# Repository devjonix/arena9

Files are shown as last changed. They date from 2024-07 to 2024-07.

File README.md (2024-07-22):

# Arena 9

Arena 9 is a camera setup for fly walking experiments.
It currently consists of three modules

- Top: Mounting for a camera and LEDs
- Middle: The actual arena (9 cm diam) and its holder
- Bottom: A lift mechanism

The arena is still under development and parts may change
(as of July 2024).

## Function of each module

### Top

The top module creates distance to the arena and acts as a mounting point
for the camera.

The LED slots allow optogenetic stimulation and
illumination of the flies.

### Middle

Contains the actual arena and its holder.
The arena slides out for easy fly loading and unloading.

The floor and ceiling are acrylic glass sheets.

### Bottom

#### A) Lift (optional)

The bottom has a elevator mechanism for moving the arena up and
down. This is needed when using a video projector and a back-projection screen to adjust the distance to the screen.

Sanded or somehow else mattefied acrylic glass sheet can act
as the back-projection screen.

## DIY manufacturing

The arena is mostly 3D printable and requires only a minimal
set of additional parts. You will need

- Any FDM 3D printer
- About 1 kg of PET-G, PLA or other filament

Tested with 0.2 mm layer height, 0.4 mm nozzle and slicer
default settings. Parts do not require supports.
Brims or rafts can be used if needed for good bed adhesion.

Required, non-printable parts

- Many M3 hex-socket screws, length 8 mm
- 3x 95 x 95 x 2 mm acrylic glass

Screw holes have tight tolerances so that the M3 screws
essentially drill in.

Yet unfixed components

- USB camera for video capture (fly tracking)
- Light sources for illumination and optogenetic activation
- A digital video projector for displaying images to the flies

## About

Original vision, set of requirements, feedback and testing by
[Alice D. Bridges](https://www.alicedbridges.uk/p/about.html)
([Juusola lab](https://cognition.sites.sheffield.ac.uk/home), University of Sheffield, UK). Modelling by DEV Joni.

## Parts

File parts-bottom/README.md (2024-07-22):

# Lift mechanism

The bottom parts make up a lift mechanism
for adjusting the distance between the arena (middle) and
a diffusive screen on which images can be back-projected.

## Lift base

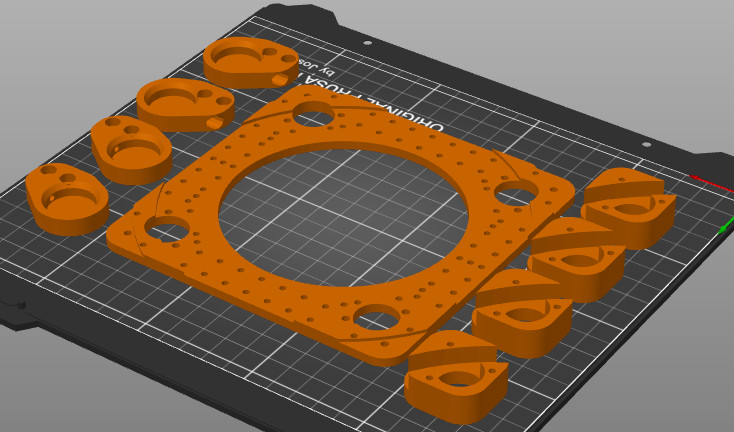
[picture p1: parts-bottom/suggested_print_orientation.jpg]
An image showing which way aroung the bottom parts should be printed Suggested print orientation


## Parts in subfolders

- Linact: A fully 3D-print linear actuator
- Sholder: The back-projection screen holder
- Gears: Gears and related tiny bits

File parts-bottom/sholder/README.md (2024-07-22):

# Screen holder

- 1x Holder
- 4x Feet A, B and C

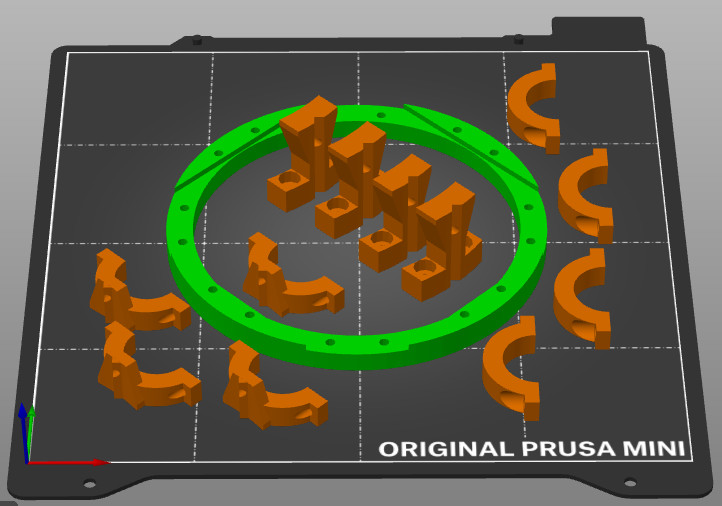
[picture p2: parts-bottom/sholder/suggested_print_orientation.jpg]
An image showing which way aroung the parts should be printed Suggested print orientation


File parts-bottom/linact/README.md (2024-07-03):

# Linear actuator

Printing

- Enable brim
- Print the adjustpiece in the orientation shown: When inserted to the outer shell, it's Z layer lines are in a 90 deg angle with respect to the lines in the rod
- Consider printing the thin section of the screw with extra perimeters and/or higher infill for increased strength

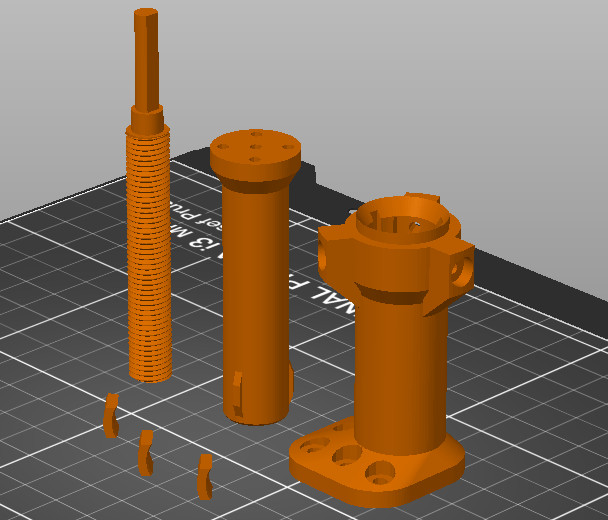
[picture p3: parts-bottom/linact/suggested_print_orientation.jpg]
An image showing which way around the parts should be printed Suggested print orientation


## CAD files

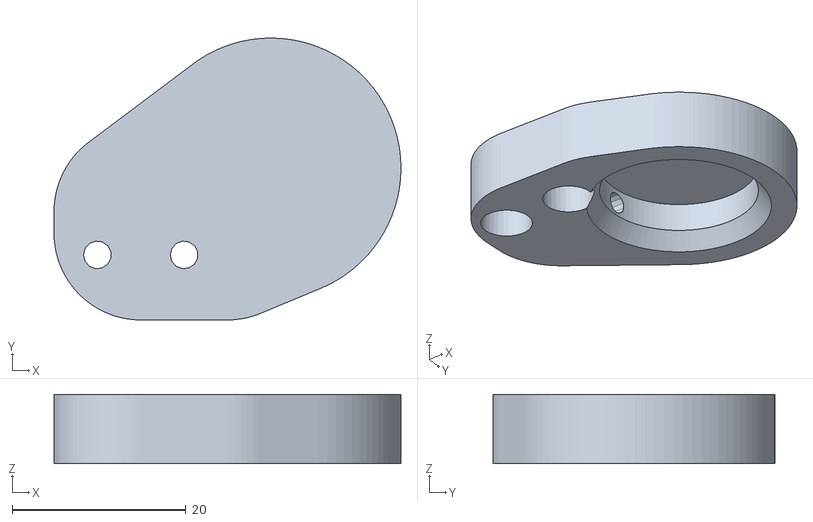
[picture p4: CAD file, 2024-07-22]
parts-bottom/bottom_arenafoot_mirrored.stl
40.0 x 32.5 x 8.01

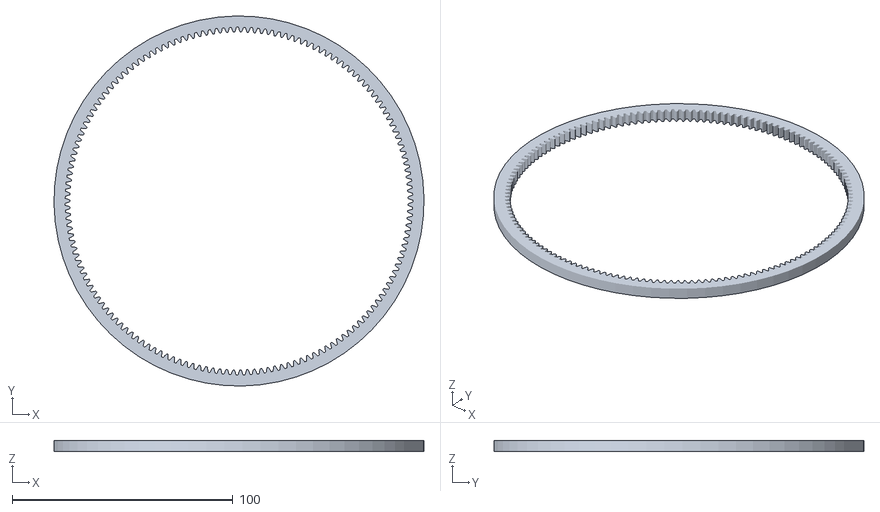
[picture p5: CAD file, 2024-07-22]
parts-bottom/gears/bottom_gear_p1.stl
167.5 x 167.5 x 5.00

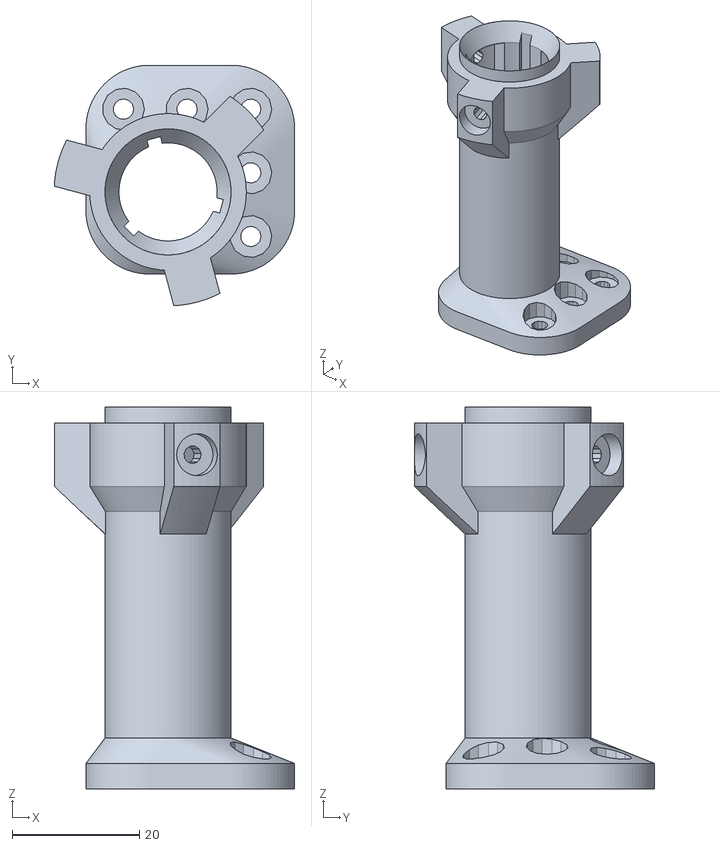
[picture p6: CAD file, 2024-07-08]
parts-bottom/linact/linact_outershell.stl
37.8 x 37.8 x 60.0

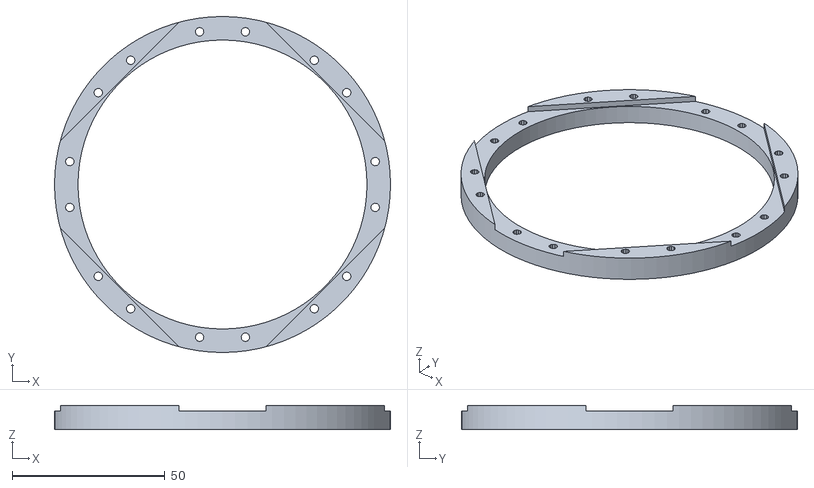
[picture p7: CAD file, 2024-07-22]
parts-bottom/sholder/bottom_screenholder.stl
110.0 x 110.0 x 8.00

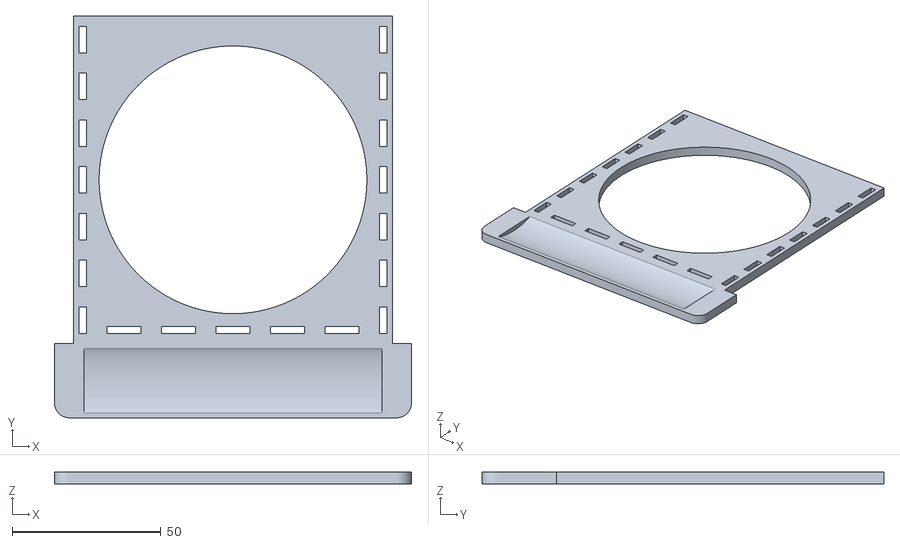
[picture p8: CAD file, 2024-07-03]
parts-middle/arena_A.stl
120.0 x 135.0 x 4.01

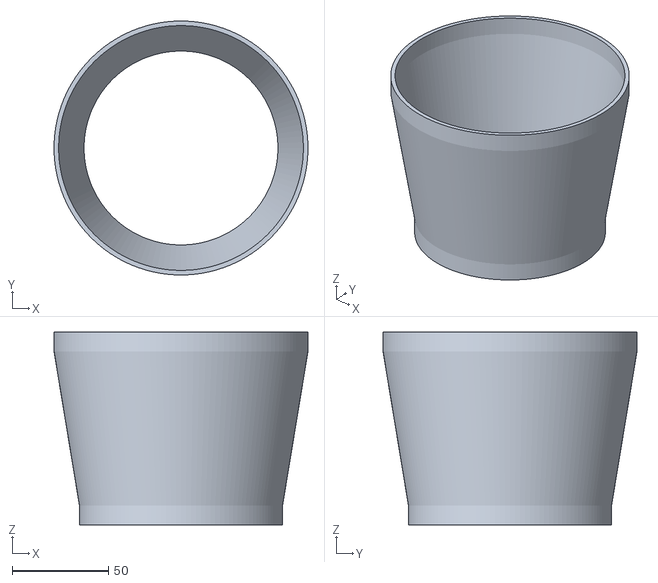
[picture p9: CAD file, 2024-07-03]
parts-top/top_tube_10cm.stl
131.8 x 131.8 x 100.0

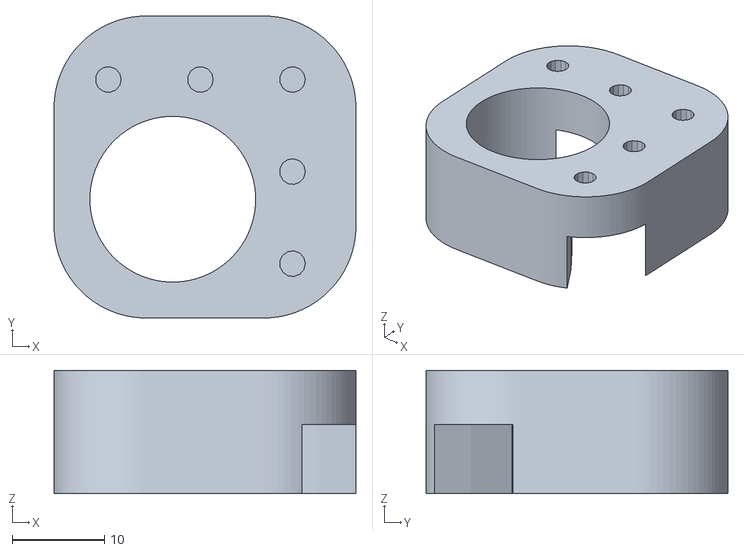
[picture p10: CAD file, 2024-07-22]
parts-bottom/bottom_linactstand.stl
32.8 x 32.8 x 13.4

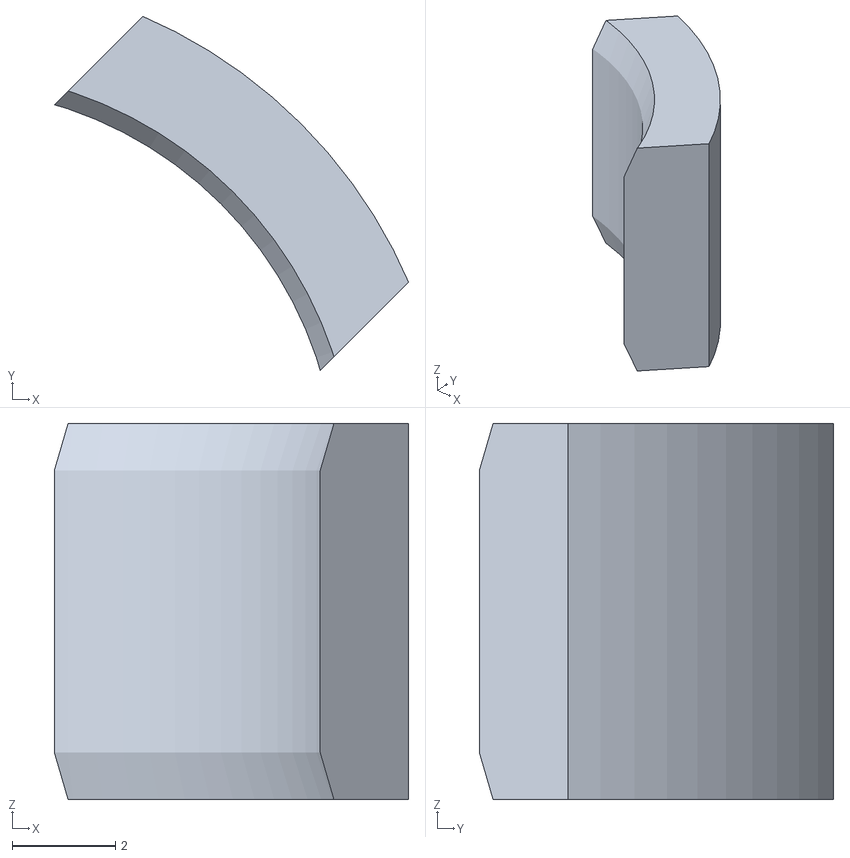
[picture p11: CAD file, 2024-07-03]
parts-bottom/linact/linact_adjustpiece.stl
6.88 x 6.88 x 7.30

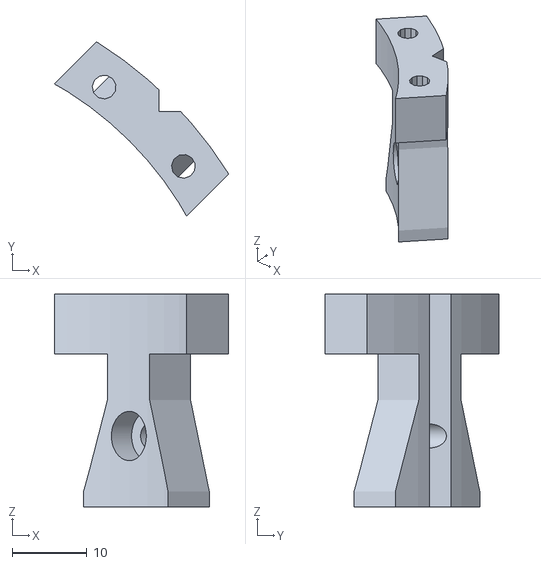
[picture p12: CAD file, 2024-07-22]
parts-bottom/sholder/bottom_screenholder_feetA.stl
23.3 x 23.3 x 28.5

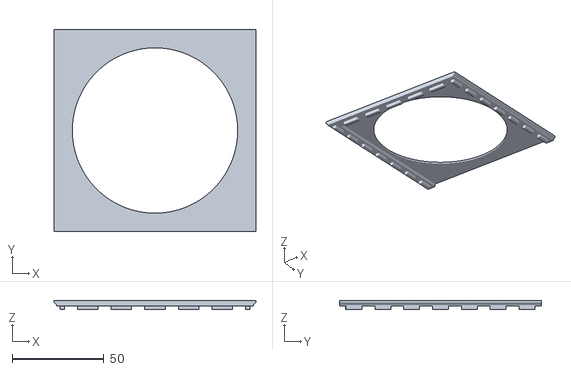
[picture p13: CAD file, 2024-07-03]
parts-middle/arena_B.stl
110.0 x 110.0 x 4.90

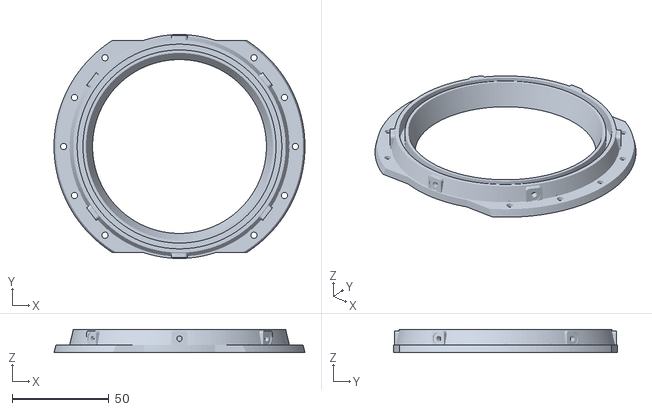
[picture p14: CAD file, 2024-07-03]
parts-top/top_bottom-ring.stl
130.0 x 116.0 x 12.0

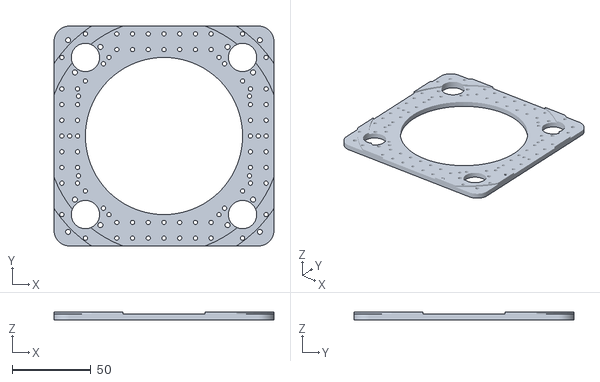
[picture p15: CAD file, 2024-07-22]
parts-bottom/bottom_liftplate.stl
140.0 x 140.0 x 5.40

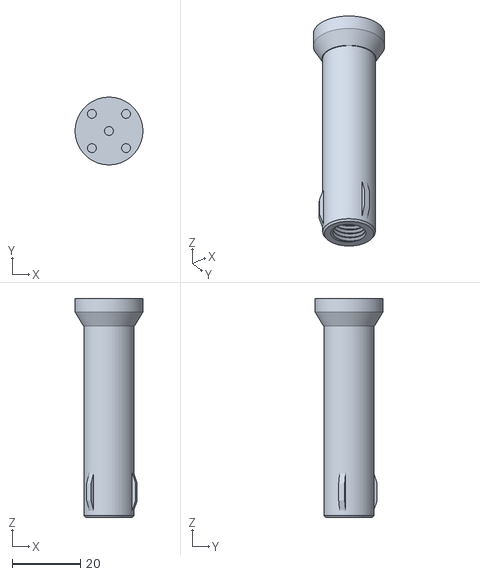
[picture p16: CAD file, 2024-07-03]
parts-bottom/linact/linact_rod.stl
19.8 x 19.8 x 64.0

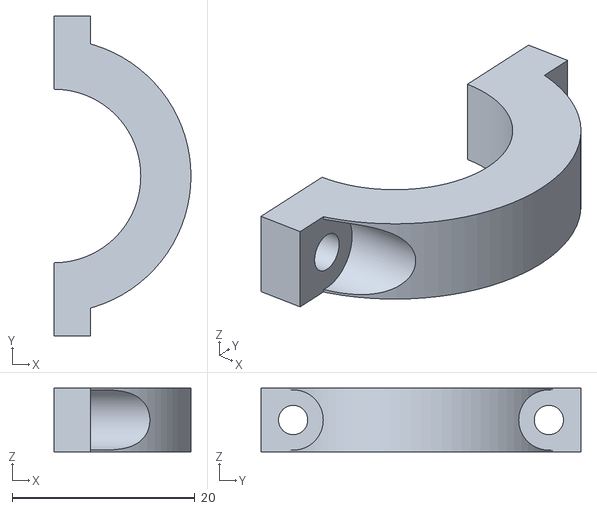
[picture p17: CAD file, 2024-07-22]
parts-bottom/sholder/bottom_screenholder_feetC.stl
15.0 x 35.0 x 7.00

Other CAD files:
parts-middle/arena_holder_lower.stl
parts-bottom/bottom_arenafoot.stl
parts-bottom/sholder/bottom_screenholder_feetB.stl
parts-middle/arena_holder_upper.stl
parts-middle/arena_holder_upper_with-extra-tol.stl
parts-middle/contactor.stl
parts-middle/contactor_v2.stl
parts-top/top_plate-camplate.stl
parts-top/top_plate-ledholder-cairn.stl
parts-top/top_plate.stl
parts-top/top_top-ring.stl
parts-top/top_tube_12cm.stl
parts-top/top_tube_8cm.stl

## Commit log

2024-07-03 Add linact adjust piece and instructions
    [linact_adjustpiece.stl, linact_outershell.stl, linact_rod.stl]
2024-07-08 Fix linact_outhershell mistakes
    [linact_outershell.stl]
2024-07-22 Add parts
    [bottom_arenafoot.stl, bottom_arenafoot_mirrored.stl, bottom_gear_p1.stl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]
2024-07-22 Add back-projection screen holder
    [bottom_screenholder.stl]
